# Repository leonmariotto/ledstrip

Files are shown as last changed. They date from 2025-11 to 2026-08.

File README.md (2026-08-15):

# Led Strip Project !

The goal here is to make a led strip controller board that just work.
Among other things the controller include a 3S battery and 4 potentiometer to control
RGBW independently.

The project layout is :
- hardware: kicad project to make the led strip controller board. Use KiCAD 9.
- cad: printable case for the controller + battery.
- software: software used to control the led strip. 
- ai: a setup to run CLI agent (codex) inside a docker with support for multiple AGENTS.md and support for KiMCP server.
- tools: tool to assist during development. Include KiMCP submodule.

## System requirements

- Must have a on/off switch
- Must have a battery properly scaled.
- Must provide a way to control color independently.
- Leds must be RGB with controllable intensity.
- Must provide a way to charge battery
- Must provide a way to program internal flash of MCU.
- Must be enclosed by a case.

## First board

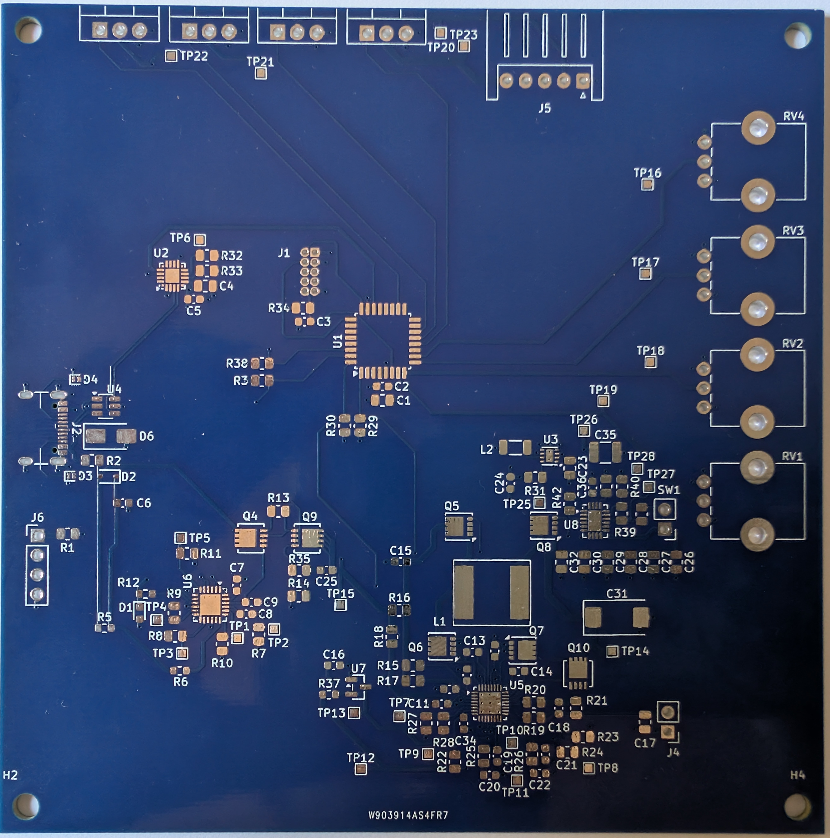
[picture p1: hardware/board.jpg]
Board without components


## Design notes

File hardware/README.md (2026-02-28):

# Hardware design for led strip controller !

## Hardware Requirements

- Must have a on/off switch
- Must provide a USB-C socket
- Must use a serie of Li-Ion battery along with a BMS
- Must use USB-C Power Delivery feature for efficient charging.
- Must use one potentiometer to control one color.
- Must provide an easy access to log via USB.
- Must support run while charging battery.
- Must provide protections against heating and short circuit.

## Ledstrip part !

Choosen RGBW ledstrip of 2 meters.
https://opencircuit.fr/produit/analog-rgbw-led-strip-rgb-plus-warm-white-60

## Hardware Architecture Design

So far the following components is identified :
- 3S Li-ion battery pack. 12V output.
- 3S BMS: off the shelf 3S (3-cells) BMS module. Shall support currents >
to expected (for 2 meter strip the expected current is 3.2A at 12V. So design it to 5-10A.
Start with an external BMS module, then progressively move into an integrated
BMS.
- USB-C connector
- USB to UART bridge (Silicon Labs CP2102(N), or FTDI FT230x or CH340)
- USB Power Delivery controller (ST STUSB4500) used to negociate high power input from USB.
- Battery charger IC (BQ25703A) : accept PD voltage and implement CC/CV.
Provide support for system load while charging.
- Buck regulator (12V to 3.3V) : integrated converter IC
- Logic-level N-MOSFETS x3, low RDS(on).
- Gate resistor / gate pull-down for each MOSFET, Fuse, ESD protections (TVS diodes, Schottky),
- Dedicated MIPI-10 connector for SWD.
- STM32G030K6 MCU.

### STM32G030K6 32-bit LQFP package

Use the following wiring :
- SWD: PA13, PA14, NRST
- UART: PA9 (TX), PA10 (RX)
- ADC (pots): PA0, PA1, PA2
- I2C to BQ25703A: PB6 (SCL), PB7 (SDA)
- PWM to MOSFET: PA8, PA6, PA7
- Power pins: VDD, VDDA, VSS, VSSA (decouple properly)
- BQ25703A_PROCHOT: PB9
- BQ25703A_CHRG_OK: PB9
Note that PWM need to use TIM1 for PA0 and TIM3 for PA6 and PA7 due to conflicts with UART.

## Building

A CI is here to build Gerber on a stable and reproducible environment.
PCBway is the recommended manufacturer.

## 4 layers

- Top (F.Cu): components + most routing (especially short local routes)
- Inner 1: solid GND plane (no splits)
- Inner 2: power pours (3.3 V, 12 V) + only necessary routing (prefer short, controlled routes)
- Bottom (B.Cu): routing + GND pour (stitched to Inner 1 often); use power pours only where it clearly helps (short distribution or local planes)

# TODO

- Create missing 3D view for footprint that lack it.
- MPN (Manufacturer Part Number) shall be included in the CI's BOM
- Generate Pick & Place (CPL/XY)
- Generate Plot Assembly Drwaing (Top/Bottom)

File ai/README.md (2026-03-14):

# AI

This setup use codex inside a container. Only this repository are visible to AI agent.
This have the advantage to give full-access to agent without security issue.
This setup support customizable AGENTS.md.

## Setup

First thing to do is to build the docker image. Go to `ai/docker` and run `./build.sh`.
Dockerfile will look for a `auth.json` file which is not committed.
You'll have to first login to codex elsewhere, and copy `auth.json` here.

## KiCad MCP server

You'll find a submodule under `tools/kimcp` that contain a MCP server implementation
for KiCad.
Container is already setup to try connect to this server.
Start the MCP server before running agents.

## Run

For usage run `ai/run.sh -h`.
Samples AGENTS.md are located in `ai/agents`.
To run with a custom agent : `./ai/run.sh -a ai/agents/kicad_helper.md`.

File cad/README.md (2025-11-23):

# CAD for led strip project !

## CAD requirements

- A plastic case must enclose PCB and battery.
- USB and LED socket shall be accessible from outside the case.
- The case must be easily disassembled using screw.
- Case must be printable on most 3D printers.

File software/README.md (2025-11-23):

# Software design for led strip controller !

## Prototype hardware list

- STM32G0 nucleo
- Led strip
- 3 potentiometer
- 3 N-channel mosfet

## Software Requirements

- Must read analog input from potentiometer.
- Must control N-channel mosfet with PWM.
- Must output log on UART.
- Must drive battery charger IC.

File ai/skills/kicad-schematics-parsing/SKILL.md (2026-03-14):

---
name: kicad-schematics-parsing
description: Parse KiCad schematics file in order to extract data or modify it.
---

# kicad-schematics-parsing

How to extract or modify data in KiCad schematics (`.kicad_sch`) without the GUI.

## Choose the interface first
- Use `kicad-cli` export plus direct `.kicad_sch` parsing for audits, field completeness, BOM/MPN checks, and low-level bulk edits.
- Use the KiCad schematic MCP server for semantic edits: add/remove components, inspect pins, add labels/wires/buses, connect pins, manage sheets, then save.
- Prefer plain parsing when correctness depends on raw file contents or when the MCP wrapper looks stale or buggy.
- Prefer MCP when the task is naturally schematic-aware, such as "connect U1 pin PB6 to R3 pin 1" or "add a resistor and label the net".

## Export structured data first
- Prefer exporting to XML (easy to parse) with `HOME=$PWD kicad-cli sch export netlist --format kicadxml
<schematic> -o /tmp/netlist.xml`.
- If the project uses custom libs, run in the project root so the project `sym-lib-table` is found. Setti
ng `HOME` to the repo avoids permission errors from KiCad trying to write under `/root`.
- For BOM-style field checks, `kicad-cli sch export bom <schematic> -o /tmp/bom.csv` can be simpler.
- Treat XML/BOM export as a first pass, not a source of truth for every custom field value. In some proje
cts the export preserves field names but drops populated per-symbol values needed for audits.

## Parsing tips (XML netlist)
- Components live under `<export><components><comp ref=...>`. Within each `<comp>` you have `<value>`, `<
footprint>`, `<description>`, `<fields>` (legacy fields) and `<property>` entries (modern properties).
- When reading a field/property, prefer `property` value, and fall back to `fields/field` if missing. Bot
h use the `name` attribute.
- Sheet hierarchy is exposed by `<sheetpath>` attributes if you need context per component.
- If expected custom values come back empty, switch to parsing the `.kicad_sch` directly before concluding
 the data is missing.

## Parsing tips (S-expression `.kicad_sch`)
- Each schematic is an S-expression rooted at `(kicad_sch ...)` with sections such as `(lib_symbols ...)`
 and many placed top-level `(symbol ...)` instances.
- Library symbols may appear under `(lib_symbols ...)`, but placed symbol instances are usually top-level `
(symbol ...)` blocks with `(property "Reference" "...")`, `(property "Value" "...")`, etc. Audit those in
stance blocks, not the library symbol definitions.
- Properties mirror what you see in XML export (`Distributor Link 1`, `Manufacturer Part Number`, etc.).
- Use an S-expression parser when available; if not, a small purpose-built parser for strings/lists is fin
e. Treat text as UTF-8.
- For edits, preserve formatting and numeric precision; KiCad is order-tolerant but stable ordering reduc
es churn.
- Ignore autosave or lock files such as `_autosave-*.kicad_sch` and `~*.lck` unless the user explicitly wa
nts them audited.

## MCP workflow
- Load the target schematic through the MCP server before making semantic edits.
- After loading, inspect with MCP methods such as component listing and pin lookup instead of recomputing symbol geometry yourself.
- For wire creation, prefer MCP connection helpers over hand-editing wires and junctions.
- Save through MCP, then validate with `kicad-cli sch export netlist` and ERC.
- If MCP fails on the real project, fall back immediately to plain parsing and `kicad-cli`; do not block on the wrapper.

## When plain parsing is better
- Auditing custom properties like `Distributor Link 1`, `Manufacturer Part Number`, and footprint completeness.
- Normalizing or bulk-editing per-symbol properties across many instances.
- Investigating hierarchy, formatting, or unusual constructs exactly as stored on disk.
- Working around MCP wrapper/API mismatches.

## Common queries
- Symbols missing a property: filter comps where `property["TargetProp"]` is empty but another property e
xists.
- Footprint completeness: ensure `Footprint`/`footprint` is set on every symbol unless intentionally excl
uded (`exclude_from_bom`/`exclude_from_board`).
- Link/MPN completeness: ensure `Distributor Link 1` and `Manufacturer Part Number` are filled for all pu
rchasing parts; headers/testpoints may be exempt.
- For link/MPN audits, check common misspellings seen in hand-edited projects too: `Distributor Link 1`, `
Disributor Link 1`, and `Ditributor Link 1`.
- Treat `Manufacturer Part Number` and `MPN` as equivalent by default; normalize field names before compar
ing.
- If a part has a distributor URL but no MPN field, you can often guess the MPN and manufacturer from the
 URL path. Example: Mouser links usually encode `/ProductDetail/<Manufacturer>/<MPN>`, DigiKey links often
 encode `/detail/<manufacturer>/<mpn>/...`, and vendor datasheet URLs may expose the MPN in the filename.

## Editing safely
- For small changes, edit the `.kicad_sch` S-expression directly: update `(property "Name" "Value")` or a
dd missing ones inside the symbol block.
- When adding properties, keep the same quoting and spacing as neighbors; avoid KiCad-specific tokens lik
e `~` unless already used.
- After edits, re-export with `kicad-cli sch export netlist --format kicadxml ...` and sanity-check count
s/fields.
- When backfilling procurement data, prefer updating the existing per-symbol instance properties instead of
 changing only library symbols.

## MCP patching notes
- Treat the MCP server as a thin wrapper around `kicad_sch_api`; if a tool fails with an attribute error, inspect the wrapper before blaming the schematic.
- Reproduce failures through the underlying Python API when possible. If `kicad_sch_api.Schematic.load(...)` works but the MCP tool fails, the bug is in the wrapper.
- In this environment, `title_block` is a `dict`, so wrapper code must use `schematic.title_block.get("title")`, not `schematic.title_block.title`.
- In this environment, some wrapper code assumed `schematic.lib_symbols` existed; use `schematic._data.get("lib_symbols", {})` if the public property is missing.
- `manage_power` is currently suspect here because the wrapper calls a missing `add_power_symbol` method. Use labels or direct file edits as fallback until patched.
- After patching the MCP server, verify by calling the exact MCP path again, not just the lower-level library.

## Checks
- ERC: `kicad-cli sch erc <schematic>` (may need project libs).
- If KiCad complains about missing global tables, copy/link required libs into the project `sym-lib-table
` or run with `HOME` set to a writable location inside the repo.

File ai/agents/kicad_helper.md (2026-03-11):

# AGENTS.md

You're an agent specialized in understand kicad hardware design projects.
You're able to parse and modify kicad files.
You're able to use kicad-cli to run kicad check.

## Workspace layout

- Project directory is `./ledstrip`. Hardware part of project is located under `hardware`.
- You'll find hardware architecture design description under `hardware/README.md` and in the
drawio schema.

## Helpful commands and checks

- Run ERC: `kicad-cli sch erc hardware/ledstrip/ledstrip.kicad_sch`
- Export BOM: `kicad-cli sch export bom hardware/ledstrip/ledstrip.kicad_sch -o /tmp/ledstrip_bom.xml`
- Export netlist for scripted checks: `kicad-cli sch export netlist hardware/ledstrip/ledstrip.kicad_sch -o /tmp/netlist.xml`
- When auditing completeness, ensure every symbol has a footprint and `Distributor Link 1` (headers/testpoints may intentionally omit distributor links).
- Project-specific library table may be required; copy global libs into the project table before running ERC so symbol libraries resolve.

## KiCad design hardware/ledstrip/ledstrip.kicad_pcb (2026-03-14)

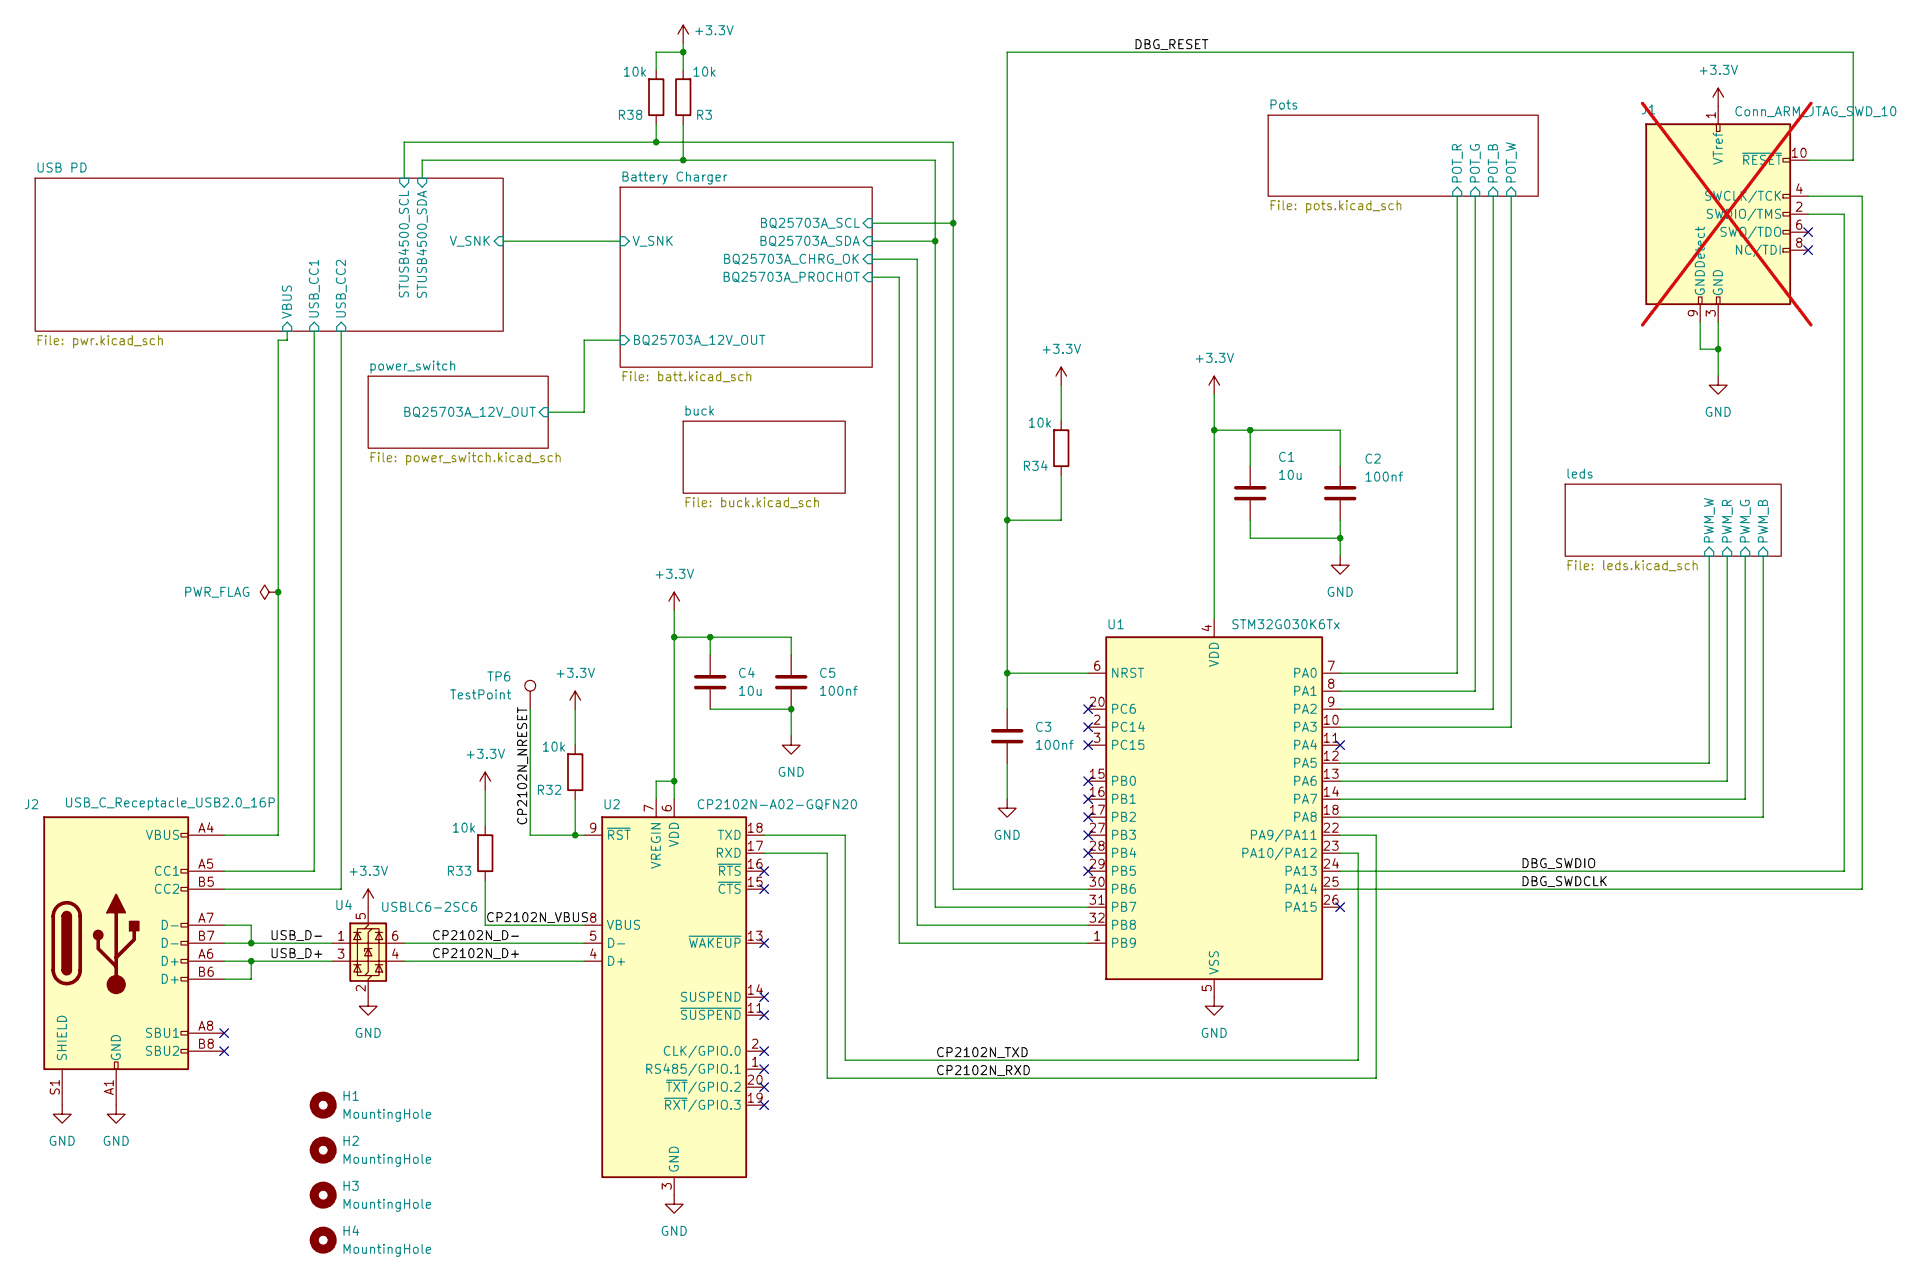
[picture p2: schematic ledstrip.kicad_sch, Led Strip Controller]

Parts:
C1, C4: 10u; C_0805_2012Metric; MPN CL21A106KAYNNN
C2, C3, C5: 100nf; C_0603_1608Metric; MPN CL10B104KA8VPJC
H1, H2, H3, H4: MountingHole; MountingHole_3.2mm_M3
J1: Conn_ARM_JTAG_SWD_10; PinHeader_2x05_P1.27mm_Vertical; not fitted
J2: USB_C_Receptacle_USB2.0_16P; USB_C_Receptacle_GCT_USB4105-xx-A_16P_TopMnt_Horizontal_PRO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; MPN USB4105-GF-A-060
R3, R32, R33, R34, R38: 10k; R_0805_2012Metric; MPN MCU0805MD1002BP500
TP6: TestPoint; TestPoint_Pad_1.0x1.0mm
U1: STM32G030K6Tx; LQFP-32_7x7mm_P0.8mm; MPN STM32G030K6T6
U2: CP2102N-A02-GQFN20; SiliconLabs_QFN-20-1EP_3x3mm_P0.5mm_EP1.8x1.8mm; MPN CP2102N-A02-GQFN20
U4: USBLC6-2SC6; SOT-23-6; MPN USBLC6-2SC6

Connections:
+3.3V: C1.1, C2.1, C4.1, C5.1, J1.1 (VTref), R3.2, R32.2, R33.2, R34.2, R38.2, U1.4 (VDD), U2.6 (VDD), U2.7 (VREGIN), U4.5 (VBUS); also elsewhere on the board
/Battery Charger/BQ25703A_CHRG_OK: U1.32 (PB8); also elsewhere on the board
/Battery Charger/BQ25703A_PROCHOT: U1.1 (PB9); also elsewhere on the board
/Battery Charger/BQ25703A_SCL: R38.1, U1.30 (PB6); also elsewhere on the board
/Battery Charger/BQ25703A_SDA: R3.1, U1.31 (PB7); also elsewhere on the board
/CP2102N_D+: U2.4 (D+), U4.4 (I/O2)
/CP2102N_D-: U2.5 (D-), U4.6 (I/O1)
/CP2102N_NRESET: R32.1, TP6.1, U2.9 (~RST)
/CP2102N_RXD: U1.22 (PA9/PA11), U2.17 (RXD)
/CP2102N_TXD: U1.23 (PA10/PA12), U2.18 (TXD)
/CP2102N_VBUS: R33.1, U2.8 (VBUS)
/DBG_RESET: C3.1, J1.10 (~RESET), R34.1, U1.6 (NRST)
/DBG_SWDCLK: J1.4 (SWCLK/TCK), U1.25 (PA14)
/DBG_SWDIO: J1.2 (SWDIO/TMS), U1.24 (PA13)
/Pots/POT_B: U1.9 (PA2); also elsewhere on the board
/Pots/POT_G: U1.8 (PA1); also elsewhere on the board
/Pots/POT_R: U1.7 (PA0); also elsewhere on the board
/Pots/POT_W: U1.10 (PA3); also elsewhere on the board
/USB PD/USB_CC1: J2.A5 (CC1); also elsewhere on the board
/USB PD/USB_CC2: J2.B5 (CC2); also elsewhere on the board
/USB PD/VBUS: J2.A4 (VBUS), J2.A9 (VBUS), J2.B4 (VBUS), J2.B9 (VBUS); also elsewhere on the board
/USB_D+: J2.A6 (D+), J2.B6 (D+), U4.3 (I/O2)
/USB_D-: J2.A7 (D-), J2.B7 (D-), U4.1 (I/O1)
/leds/PWM_B: U1.18 (PA8); also elsewhere on the board
/leds/PWM_G: U1.14 (PA7); also elsewhere on the board
/leds/PWM_R: U1.13 (PA6); also elsewhere on the board
/leds/PWM_W: U1.12 (PA5); also elsewhere on the board
GND: C1.2, C2.2, C3.2, C4.2, C5.2, J1.3 (GND), J1.5 (GND), J1.9 (GNDDetect), J2.A1 (GND), J2.A12 (GND), J2.B1 (GND), J2.B12 (GND), J2.S1 (SHIELD), U1.5 (VSS), U2.3 (GND), U2.12 (GND), U2.21 (GND), U4.2 (GND); also elsewhere on the board

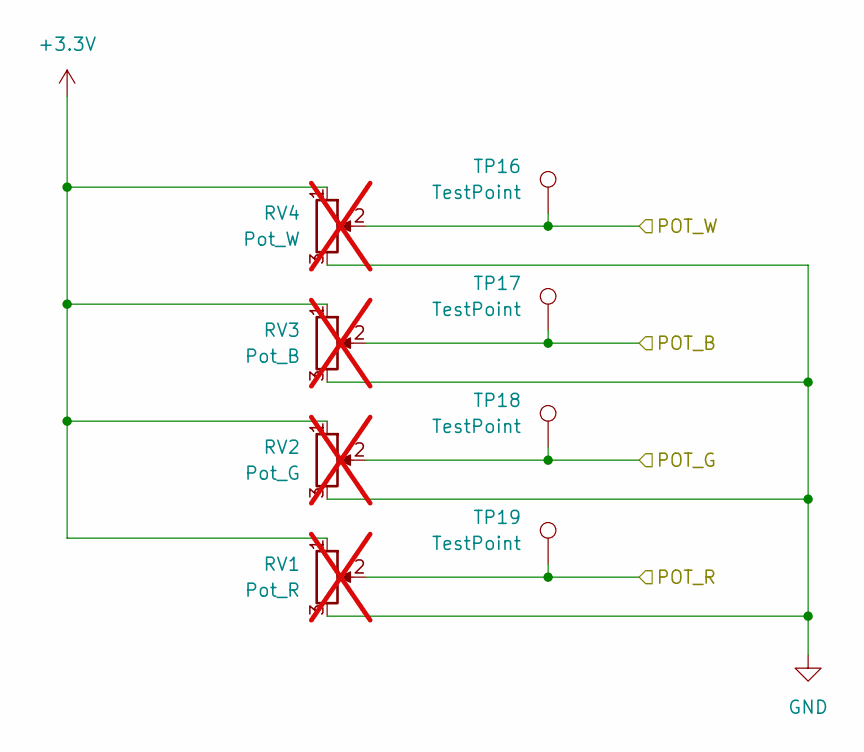
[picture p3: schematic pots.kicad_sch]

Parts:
RV1: Pot_R; Potentiometer_Bourns_PTV09A-1_Single_Vertical; MPN PTV09A-6030U-B103; not fitted
RV2: Pot_G; Potentiometer_Bourns_PTV09A-1_Single_Vertical; MPN PTV09A-6030U-B103; not fitted
RV3: Pot_B; Potentiometer_Bourns_PTV09A-1_Single_Vertical; MPN PTV09A-6030U-B103; not fitted
RV4: Pot_W; Potentiometer_Bourns_PTV09A-1_Single_Vertical; MPN PTV09A-6030U-B103; not fitted
TP16, TP17, TP18, TP19: TestPoint; TestPoint_Pad_1.0x1.0mm

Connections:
+3.3V: RV1.1, RV2.1, RV3.1, RV4.1; also elsewhere on the board
/Pots/POT_B: RV3.2, TP17.1; also elsewhere on the board
/Pots/POT_G: RV2.2, TP18.1; also elsewhere on the board
/Pots/POT_R: RV1.2, TP19.1; also elsewhere on the board
/Pots/POT_W: RV4.2, TP16.1; also elsewhere on the board
GND: RV1.3, RV2.3, RV3.3, RV4.3; also elsewhere on the board

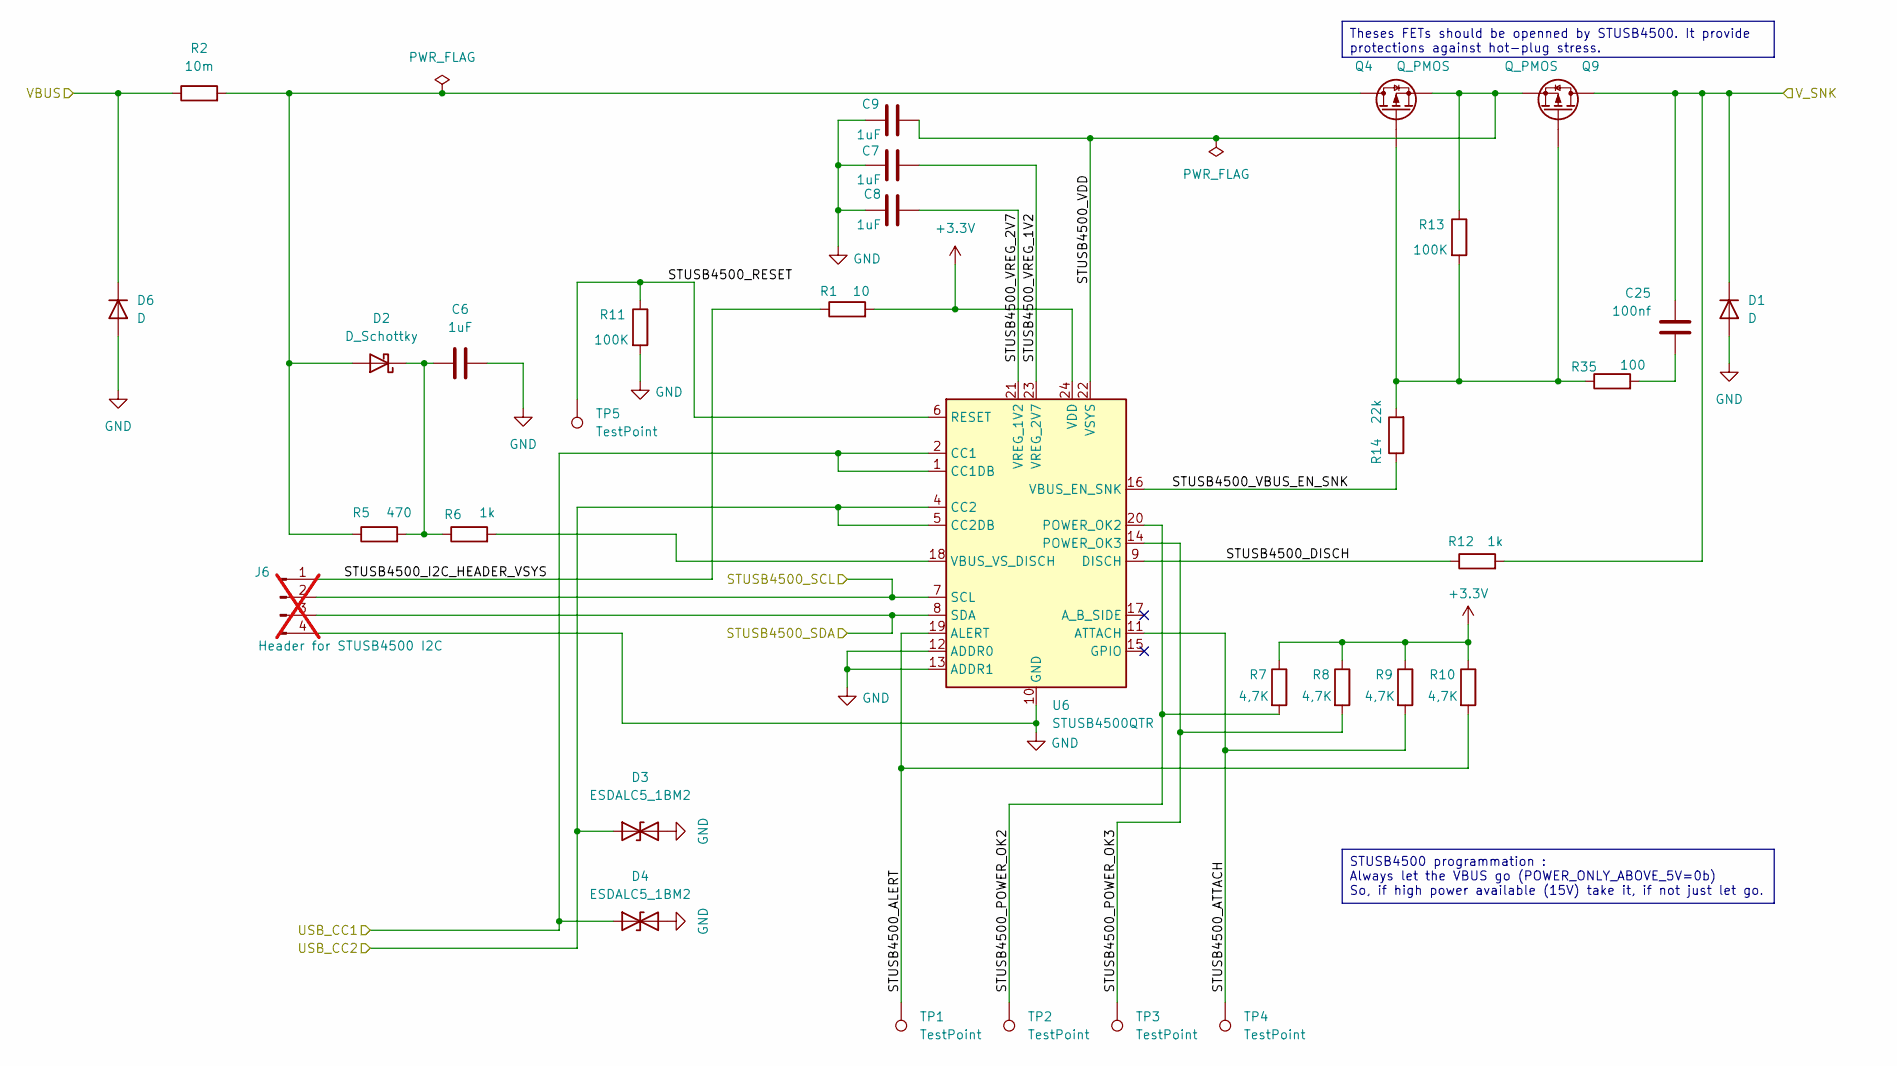
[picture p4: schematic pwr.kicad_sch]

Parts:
C6, C7, C8, C9: 1uF; C_0603_1608Metric; MPN 885012106022
C25: 100nf; C_0603_1608Metric; MPN CL10B104KA8VPJC
D1: D; D_0603_1608Metric; MPN ESDA20P50-1U1M
D2: D_Schottky; D_SOD-323; MPN BAT54JFILM
D3, D4: ESDALC5_1BM2; D_SOD-882; MPN ESDALC5-1BT2
D6: D; D_SMA; MPN SMAJ15AHM3_A-H
J6: Header for STUSB4500 I2C; PinHeader_1x04_P2.54mm_Vertical; not fitted
Q4, Q9: Q_PMOS; POWERFLAT_3P3X3P3_STM; MPN STL6P3LLH6
R1: 10; R_0805_2012Metric; MPN CRCW080510R0JNEAHP
R2: 10m; R_0805_2012Metric; MPN WSLP0805R0100DEA
R5: 470; R_0603_1608Metric; MPN SFR03EZPJ471
R6, R12: 1k; R_0603_1608Metric; MPN RCA06031K00FKEAHP
R7, R8, R9, R10: 4,7K; R_0805_2012Metric; MPN ERA-6ARW472V
R11, R13: 100K; R_0805_2012Metric; MPN RT0805BRB07100KL
R14: 22k; R_0805_2012Metric; MPN MCU08050C2202FP500
R35: 100; R_0805_2012Metric; MPN RP0805CT-1000GN-96TR
TP1, TP2, TP3, TP4, TP5: TestPoint; TestPoint_Pad_1.0x1.0mm
U6: STUSB4500QTR; QFN-24-1EP_4x4mm_P0.5mm_EP2.7x2.7mm; MPN STUSB4500QTR

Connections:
+3.3V: R1.2, R7.1, R8.1, R9.1, R10.1, U6.24 (VDD); also elsewhere on the board
/Battery Charger/BQ25703A_SCL: J6.2, U6.7 (SCL); also elsewhere on the board
/Battery Charger/BQ25703A_SDA: J6.3, U6.8 (SDA); also elsewhere on the board
/Battery Charger/V_SNK: C25.1, D1.1 (K), Q9.D, R12.2; also elsewhere on the board
/USB PD/STUSB4500_ALERT: R10.2, TP1.1, U6.19 (ALERT)
/USB PD/STUSB4500_ATTACH: R9.2, TP4.1, U6.11 (ATTACH)
/USB PD/STUSB4500_DISCH: R12.1, U6.9 (DISCH)
/USB PD/STUSB4500_I2C_HEADER_VSYS: J6.1, R1.1
/USB PD/STUSB4500_POWER_OK2: R7.2, TP2.1, U6.20 (POWER_OK2)
/USB PD/STUSB4500_POWER_OK3: R8.2, TP3.1, U6.14 (POWER_OK3)
/USB PD/STUSB4500_RESET: R11.1, TP5.1, U6.6 (RESET)
/USB PD/STUSB4500_VBUS_EN_SNK: R14.1, U6.16 (VBUS_EN_SNK)
/USB PD/STUSB4500_VDD: C9.2, Q4.S, Q9.S, R13.1, U6.22 (VSYS)
/USB PD/STUSB4500_VREG_1V2: C7.1, U6.23 (VREG_2V7)
/USB PD/STUSB4500_VREG_2V7: C8.1, U6.21 (VREG_1V2)
/USB PD/USB_CC1: D4.1 (A1), U6.1 (CC1DB), U6.2 (CC1); also elsewhere on the board
/USB PD/USB_CC2: D3.1 (A1), U6.4 (CC2), U6.5 (CC2DB); also elsewhere on the board
/USB PD/VBUS: D6.1 (K), R2.1; also elsewhere on the board
GND: C6.2, C7.2, C8.2, C9.1, D1.2 (A), D3.2 (A2), D4.2 (A2), D6.2 (A), J6.4, R11.2, U6.10 (GND), U6.12 (ADDR0), U6.13 (ADDR1), U6.25 (GND); also elsewhere on the board
unnamed: C25.2, R35.2
unnamed: D2.2 (A), Q4.D, R2.2, R5.1
unnamed: C6.1, D2.1 (K), R5.2, R6.1
unnamed: Q4.G, Q9.G, R13.2, R14.2, R35.1
unnamed: R6.2, U6.18 (VBUS_VS_DISCH)

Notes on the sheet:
Theses FETs should be openned by STUSB4500. It provide protections against hot-plug stress.
STUSB4500 programmation : Always let the VBUS go (POWER_ONLY_ABOVE_5V=0b) So, if high power available (15V) take it, if not just let go.

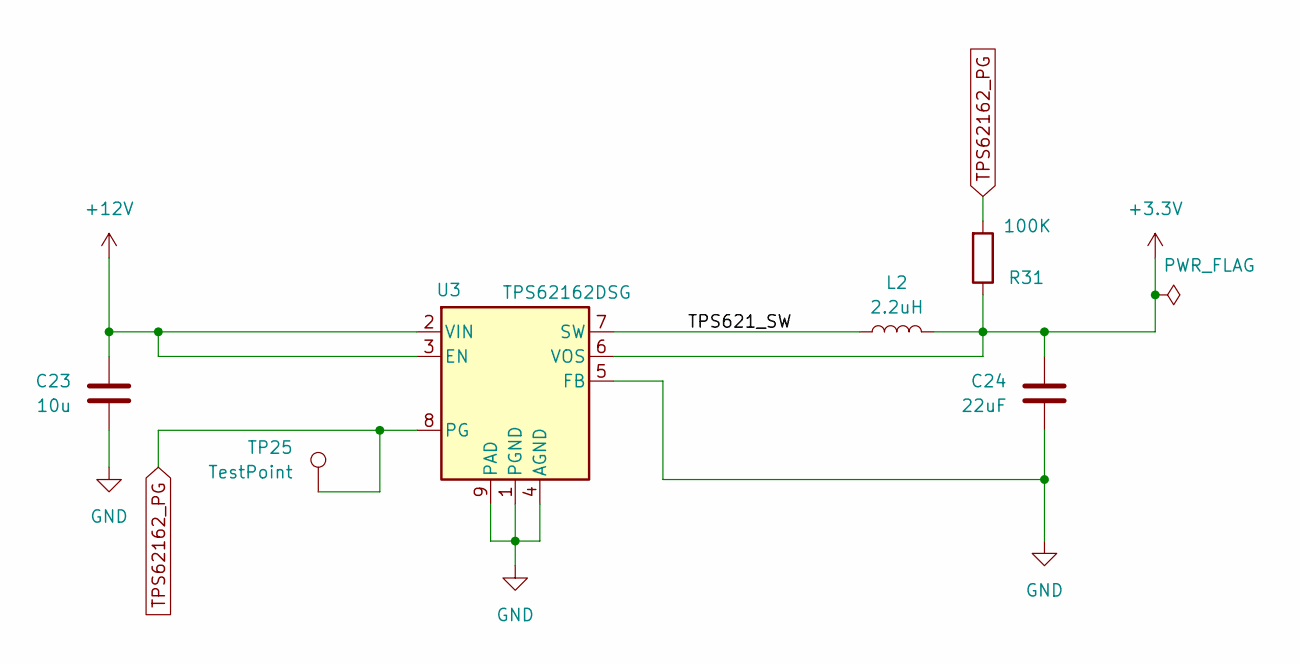
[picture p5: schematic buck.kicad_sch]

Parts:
C23: 10u; C_0805_2012Metric; MPN CL21A106KAYNNN
C24: 22uF; C_0603_1608Metric; MPN CL10Z226MS96PNC
L2: 2.2uH; L_1206_3216Metric; MPN PFL3215-222MEC
R31: 100K; R_0805_2012Metric; MPN RT0805BRB07100KL
TP25: TestPoint; TestPoint_Pad_1.0x1.0mm
U3: TPS62162DSG; WSON-8-1EP_2x2mm_P0.5mm_EP0.9x1.6mm_ThermalVias; MPN TPS62162DSGT

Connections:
+3.3V: C24.1, L2.2, R31.1, U3.6 (VOS); also elsewhere on the board
+12V: C23.1, U3.2 (VIN), U3.3 (EN); also elsewhere on the board
/buck/TPS621_SW: L2.1, U3.7 (SW)
GND: C23.2, C24.2, U3.1 (PGND), U3.4 (AGND), U3.5 (FB), U3.9 (PAD); also elsewhere on the board
TPS62162_PG: R31.2, TP25.1, U3.8 (PG)

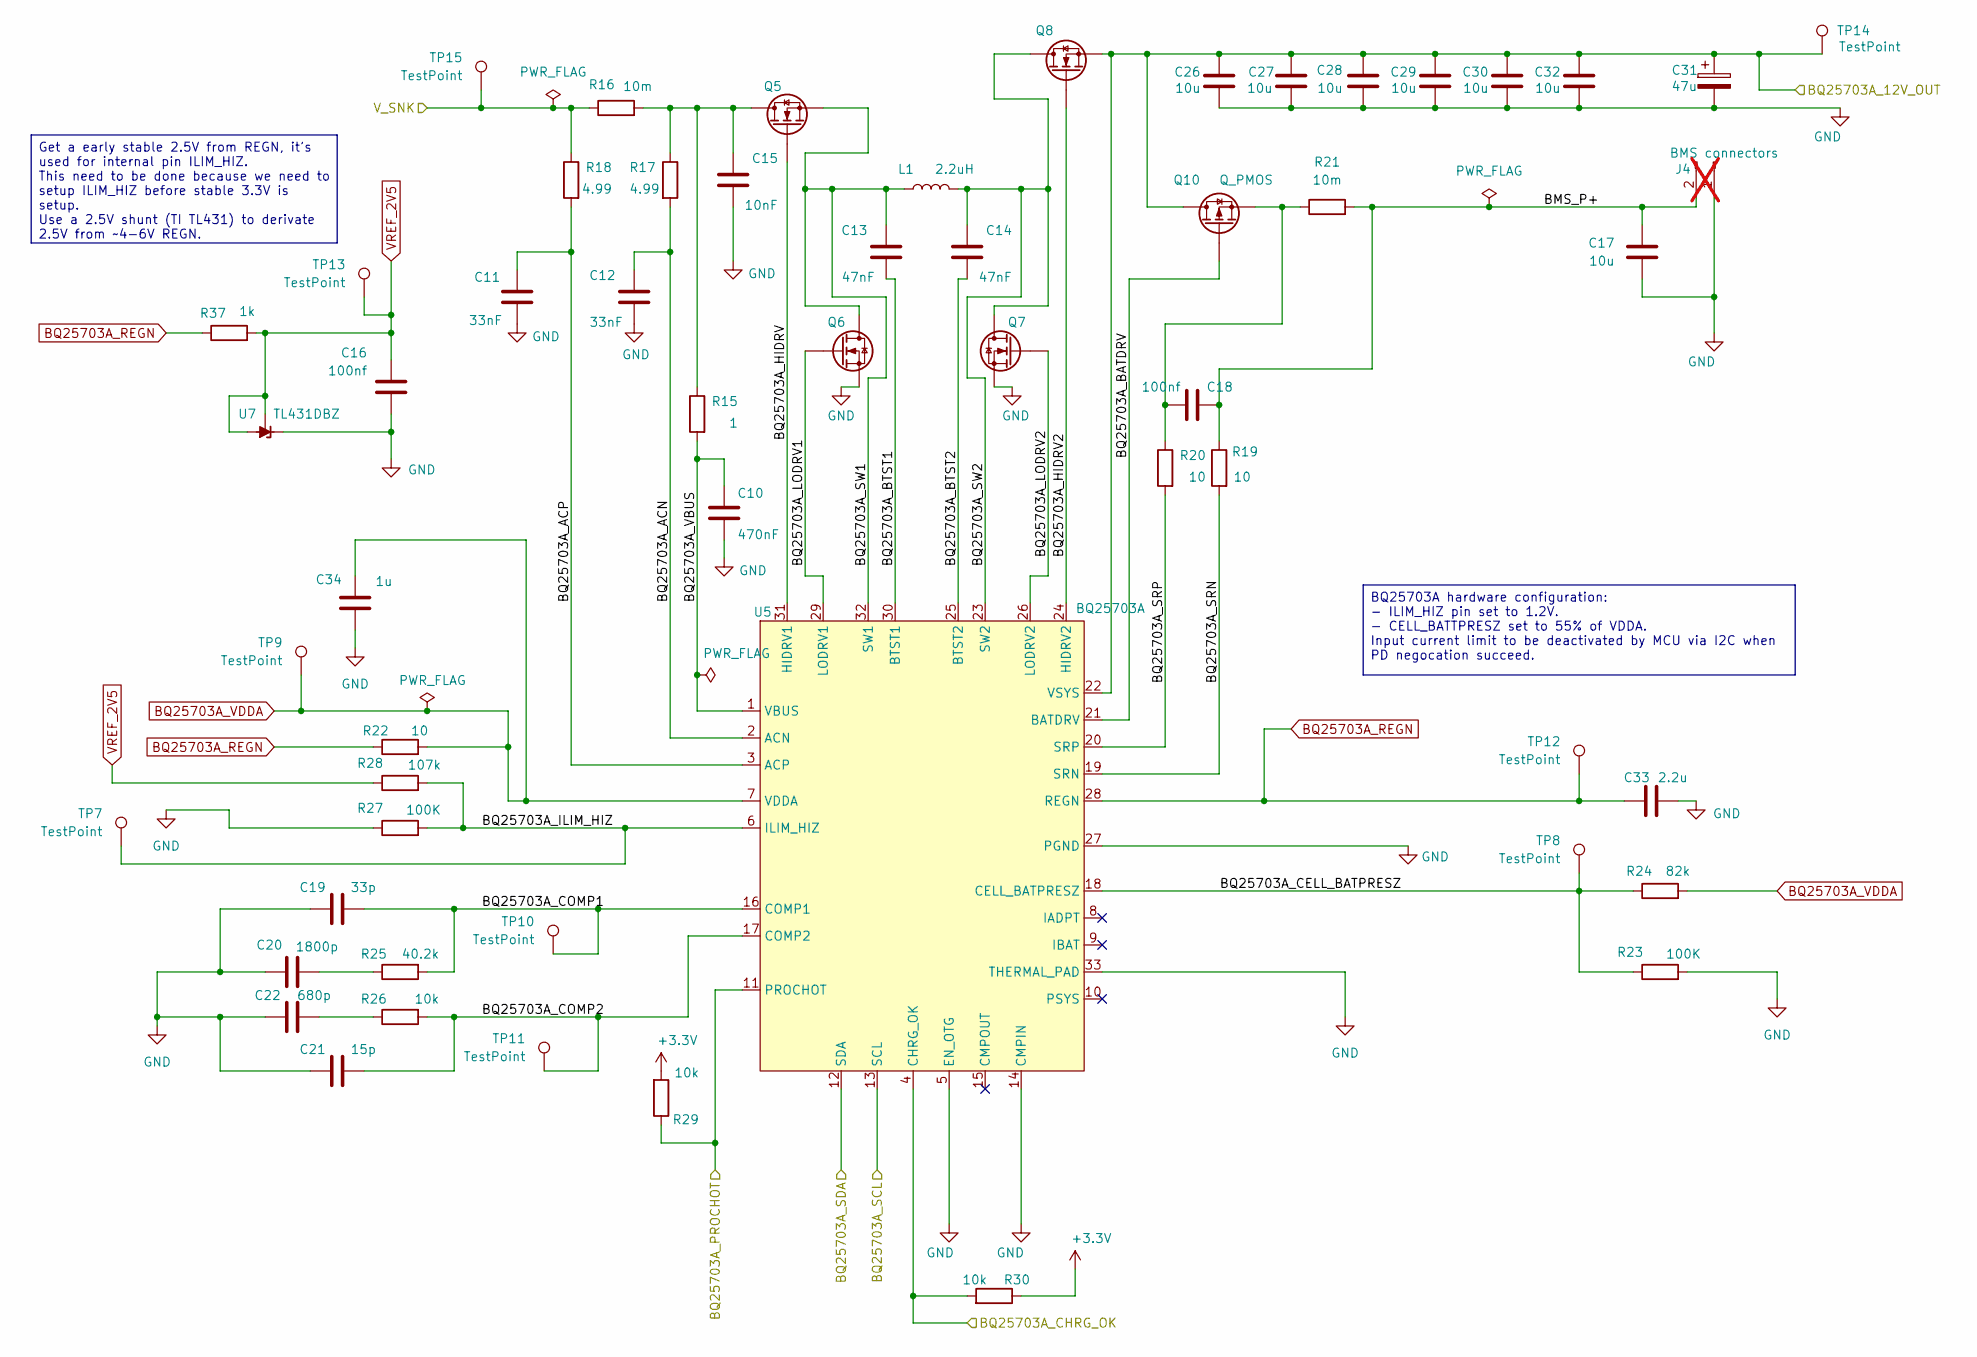
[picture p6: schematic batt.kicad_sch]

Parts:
C10: 470nF; C_0603_1608Metric; MPN C0603C474J3RACTU
C11, C12: 33nF; C_0603_1608Metric; MPN 06031C333KAT2A
C13, C14: 47nF; C_0603_1608Metric; MPN KGM15AR51V473KT
C15: 10nF; C_0603_1608Metric; MPN 03028-BR103YKU-J
C16, C18: 100nf; C_0603_1608Metric; MPN CL10B104KA8VPJC
C17, C26, C27, C28, C29, C30, C32: 10u; C_0805_2012Metric; MPN CL21A106KAYNNN
C19: 33p; C_0603_1608Metric; MPN KGQ15ACG2A330GT
C20: 1800p; C_0603_1608Metric; MPN VJ0603Y182JXAAC
C21: 15p; C_0603_1608Metric; MPN 06031U150JAT2A
C22: 680p; C_0603_1608Metric; MPN VJ0603A681GXAAC
C31: 47u; CP_EIA-7343-20_Kemet-V; MPN 20TQC47MYF
C33: 2.2u; C_0603_1608Metric; MPN CL03A225MO5C65C
C34: 1u; C_0603_1608Metric; MPN AMK063AC6105MP-F
J4: BMS connectors; PinHeader_1x02_P2.54mm_Vertical; not fitted
L1: 2.2uH; L_Wurth_WE-LHMI-8030_9.7x8.5mm; MPN 74437356022
Q5, Q6, Q7, Q8: Q_NMOS; VSON-8_3.3x3.3mm_P0.65mm_NexFET; MPN CSD17551Q3A
Q10: Q_PMOS; POWERFLAT_3P3X3P3_STM; MPN STL6P3LLH6
R15: 1; R_0805_2012Metric; MPN AC0805FR-071RL
R16, R21: 10m; R_0805_2012Metric; MPN WSLP0805R0100DEA
R17, R18: 4.99; R_0805_2012Metric; MPN CRCW08054R99DKEAHP
R19, R20: 10; R_0805_2012Metric; MPN MCU0805MC1009FP500
R22: 10; R_0805_2012Metric; MPN CRCW080510R0JNEAHP
R23, R27: 100K; R_0805_2012Metric; MPN RT0805BRB07100KL
R24: 82k; R_0805_2012Metric; MPN ERA-6ARB823V
R25: 40.2k; R_0805_2012Metric; MPN PHP00805E40R2BST1
R26, R29, R30: 10k; R_0805_2012Metric; MPN MCU0805MD1002BP500
R28: 107k; R_0805_2012Metric; MPN CRCW0805107KFKEA
R37: 1k; R_0603_1608Metric; MPN RCA06031K00FKEAHP
TP7, TP8, TP9, TP10, TP11, TP12, TP13, TP14, TP15: TestPoint; TestPoint_Pad_1.0x1.0mm
U5: BQ25703A; Texas_RSN_WQFN-32-1EP_4x4mm_P0.4mm_EP2.8x2.8mm_ThermalVias; MPN BQ25703ARSNR
U7: TL431DBZ; SOT-23; MPN TL431AQDBZR

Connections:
+3.3V: R29.2, R30.1; also elsewhere on the board
/Battery Charger/BMS_P+: C17.1, C18.2, J4.2, R19.1, R21.2
/Battery Charger/BQ25703A_12V_OUT: C26.1, C27.1, C28.1, C29.1, C30.1, C31.1, C32.1, Q8.S, Q10.D, TP14.1, U5.22 (VSYS); also elsewhere on the board
/Battery Charger/BQ25703A_ACN: C12.2, R17.2, U5.2 (ACN)
/Battery Charger/BQ25703A_ACP: C11.2, R18.2, U5.3 (ACP)
/Battery Charger/BQ25703A_BATDRV: Q10.G, U5.21 (BATDRV)
/Battery Charger/BQ25703A_BTST1: C13.1, U5.30 (BTST1)
/Battery Charger/BQ25703A_BTST2: C14.1, U5.25 (BTST2)
/Battery Charger/BQ25703A_CELL_BATPRESZ: R23.1, R24.1, TP8.1, U5.18 (CELL_BATPRESZ)
/Battery Charger/BQ25703A_CHRG_OK: R30.2, U5.4 (CHRG_OK); also elsewhere on the board
/Battery Charger/BQ25703A_COMP1: C19.1, R25.2, TP10.1, U5.16 (COMP1)
/Battery Charger/BQ25703A_COMP2: C21.1, R26.2, TP11.1, U5.17 (COMP2)
/Battery Charger/BQ25703A_HIDRV: Q5.G, U5.31 (HIDRV1)
/Battery Charger/BQ25703A_HIDRV2: Q8.G, U5.24 (HIDRV2)
/Battery Charger/BQ25703A_ILIM_HIZ: R27.2, R28.2, TP7.1, U5.6 (ILIM_HIZ)
/Battery Charger/BQ25703A_LODRV1: Q6.G, U5.29 (LODRV1)
/Battery Charger/BQ25703A_LODRV2: Q7.G, U5.26 (LODRV2)
/Battery Charger/BQ25703A_PROCHOT: R29.1, U5.11 (PROCHOT); also elsewhere on the board
/Battery Charger/BQ25703A_SCL: U5.13 (SCL); also elsewhere on the board
/Battery Charger/BQ25703A_SDA: U5.12 (SDA); also elsewhere on the board
/Battery Charger/BQ25703A_SRN: R19.2, U5.19 (SRN)
/Battery Charger/BQ25703A_SRP: R20.2, U5.20 (SRP)
/Battery Charger/BQ25703A_SW1: C13.2, L1.1, Q5.S, Q6.D, U5.32 (SW1)
/Battery Charger/BQ25703A_SW2: C14.2, L1.2, Q7.D, Q8.D, U5.23 (SW2)
/Battery Charger/BQ25703A_VBUS: C10.2, R15.2, U5.1 (VBUS)
/Battery Charger/V_SNK: R16.1, R18.1, TP15.1; also elsewhere on the board
BQ25703A_REGN: C33.1, R22.1, R37.1, TP12.1, U5.28 (REGN)
BQ25703A_VDDA: C34.1, R22.2, R24.2, TP9.1, U5.7 (VDDA)
GND: C10.1, C11.1, C12.1, C15.1, C16.2, C17.2, C19.2, C20.2, C21.2, C22.2, C26.2, C27.2, C28.2, C29.2, C30.2, C31.2, C32.2, C33.2, C34.2, J4.1, Q6.S, Q7.S, R23.2, R27.1, U5.5 (EN_OTG), U5.14 (CMPIN), U5.27 (PGND), U5.33 (THERMAL_PAD), U7.1 (K); also elsewhere on the board
unnamed: C15.2, Q5.D, R15.1, R16.2, R17.1
unnamed: C18.1, Q10.S, R20.1, R21.1
unnamed: C20.1, R25.1
unnamed: C22.1, R26.1
VREF_2V5: C16.1, R28.1, R37.2, TP13.1, U7.2 (REF), U7.3 (A)

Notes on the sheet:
Get a early stable 2.5V from REGN, it's used for internal pin ILIM_HIZ. This need to be done because we need to setup ILIM_HIZ before stable 3.3V is setup. Use a 2.5V shunt (TI TL431) to derivate 2.5V from ~4-6V REGN.
BQ25703A hardware configuration: - ILIM_HIZ pin set to 1.2V. - CELL_BATTPRESZ set to 55% of VDDA. Input current limit to be deactivated by MCU via I2C when PD negocation succeed.

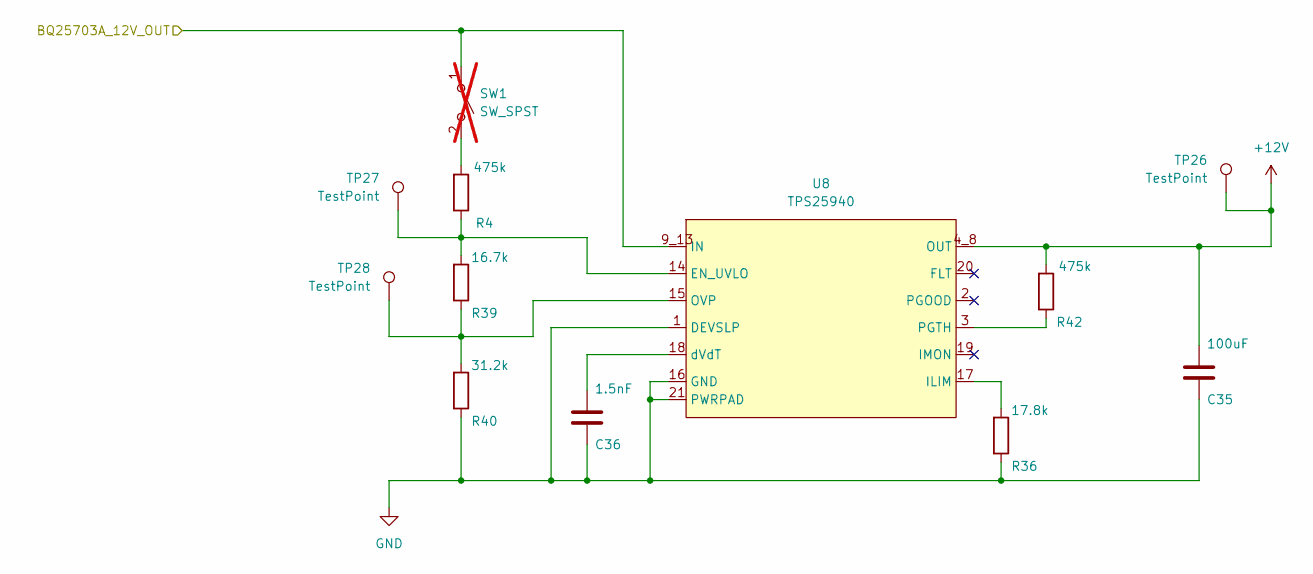
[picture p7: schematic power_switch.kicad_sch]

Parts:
C35: 100uF; C_1210_3225Metric; MPN MLASE32MAB5107MPNA01
C36: 1.5nF; C_0603_1608Metric; MPN GRT033R61A152KE01D
R4, R42: 475k; R_0805_2012Metric; MPN CRCW0805475KFHEAP
R36: 17.8k; R_0805_2012Metric; MPN TNPW080517K8BETY
R39: 16.7k; R_0805_2012Metric; MPN TNPW080516K7BEEN
R40: 31.2k; R_0805_2012Metric; MPN TNPW080531K2BEEN
SW1: SW_SPST; PinHeader_1x02_P2.54mm_Vertical; MPN SW3001A; not fitted
TP26, TP27, TP28: TestPoint; TestPoint_Pad_1.0x1.0mm
U8: TPS25940; QFN-20-1EP_3x4mm_P0.5mm_EP1.65x2.65mm_ThermalVias_PROJECTCO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; MPN TPS25940ARVCT

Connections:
+12V: C35.1, R42.2, TP26.1, U8.4_8 (OUT); also elsewhere on the board
/Battery Charger/BQ25703A_12V_OUT: SW1.1 (A), U8.9_13 (IN); also elsewhere on the board
GND: C35.2, C36.2, R36.1, R40.1, U8.1 (DEVSLP), U8.16 (GND), U8.21 (PWRPAD); also elsewhere on the board
unnamed: R4.2, SW1.2 (B)
unnamed: R4.1, R39.2, TP27.1, U8.14 (EN_UVLO)
unnamed: R36.2, U8.17 (ILIM)
unnamed: R39.1, R40.2, TP28.1, U8.15 (OVP)
unnamed: R42.1, U8.3 (PGTH)
unnamed: C36.1, U8.18 (dVdT)

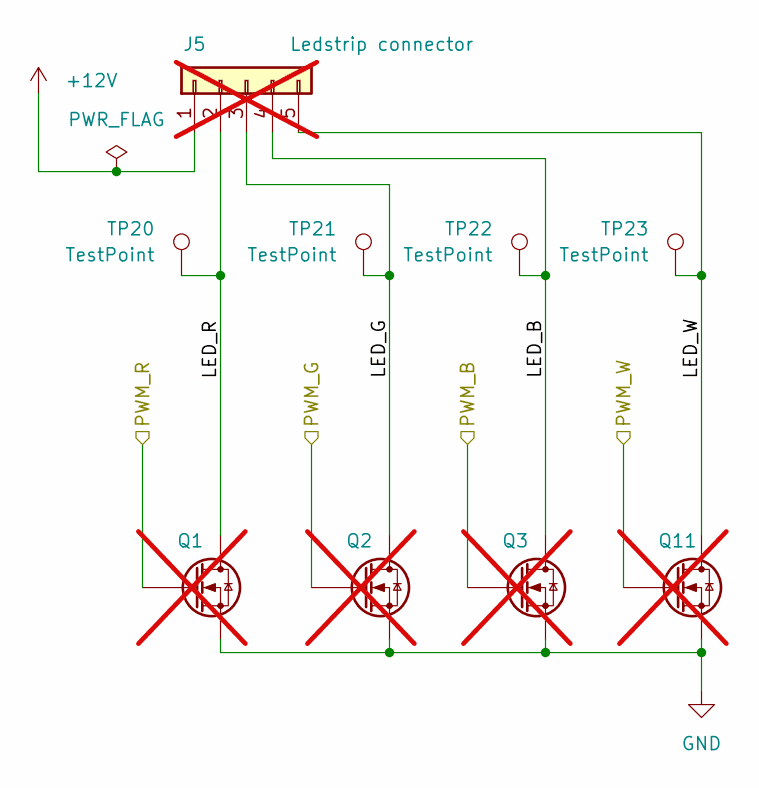
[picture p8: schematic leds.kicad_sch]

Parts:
J5: Ledstrip connector; JST_XH_S5B-XH-A_1x05_P2.50mm_Horizontal; MPN S5B-XH-A-1(LF)(SN); not fitted
Q1, Q2, Q3, Q11: Q_NMOS; TO-220-3_Vertical; MPN IRL3705NPBF; not fitted
TP20, TP21, TP22, TP23: TestPoint; TestPoint_Pad_1.0x1.0mm

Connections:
+12V: J5.1; also elsewhere on the board
/leds/LED_B: J5.4, Q3.D, TP22.1
/leds/LED_G: J5.3, Q2.D, TP21.1
/leds/LED_R: J5.2, Q1.D, TP20.1
/leds/LED_W: J5.5, Q11.D, TP23.1
/leds/PWM_B: Q3.G; also elsewhere on the board
/leds/PWM_G: Q2.G; also elsewhere on the board
/leds/PWM_R: Q1.G; also elsewhere on the board
/leds/PWM_W: Q11.G; also elsewhere on the board
GND: Q1.S, Q2.S, Q3.S, Q11.S; also elsewhere on the board

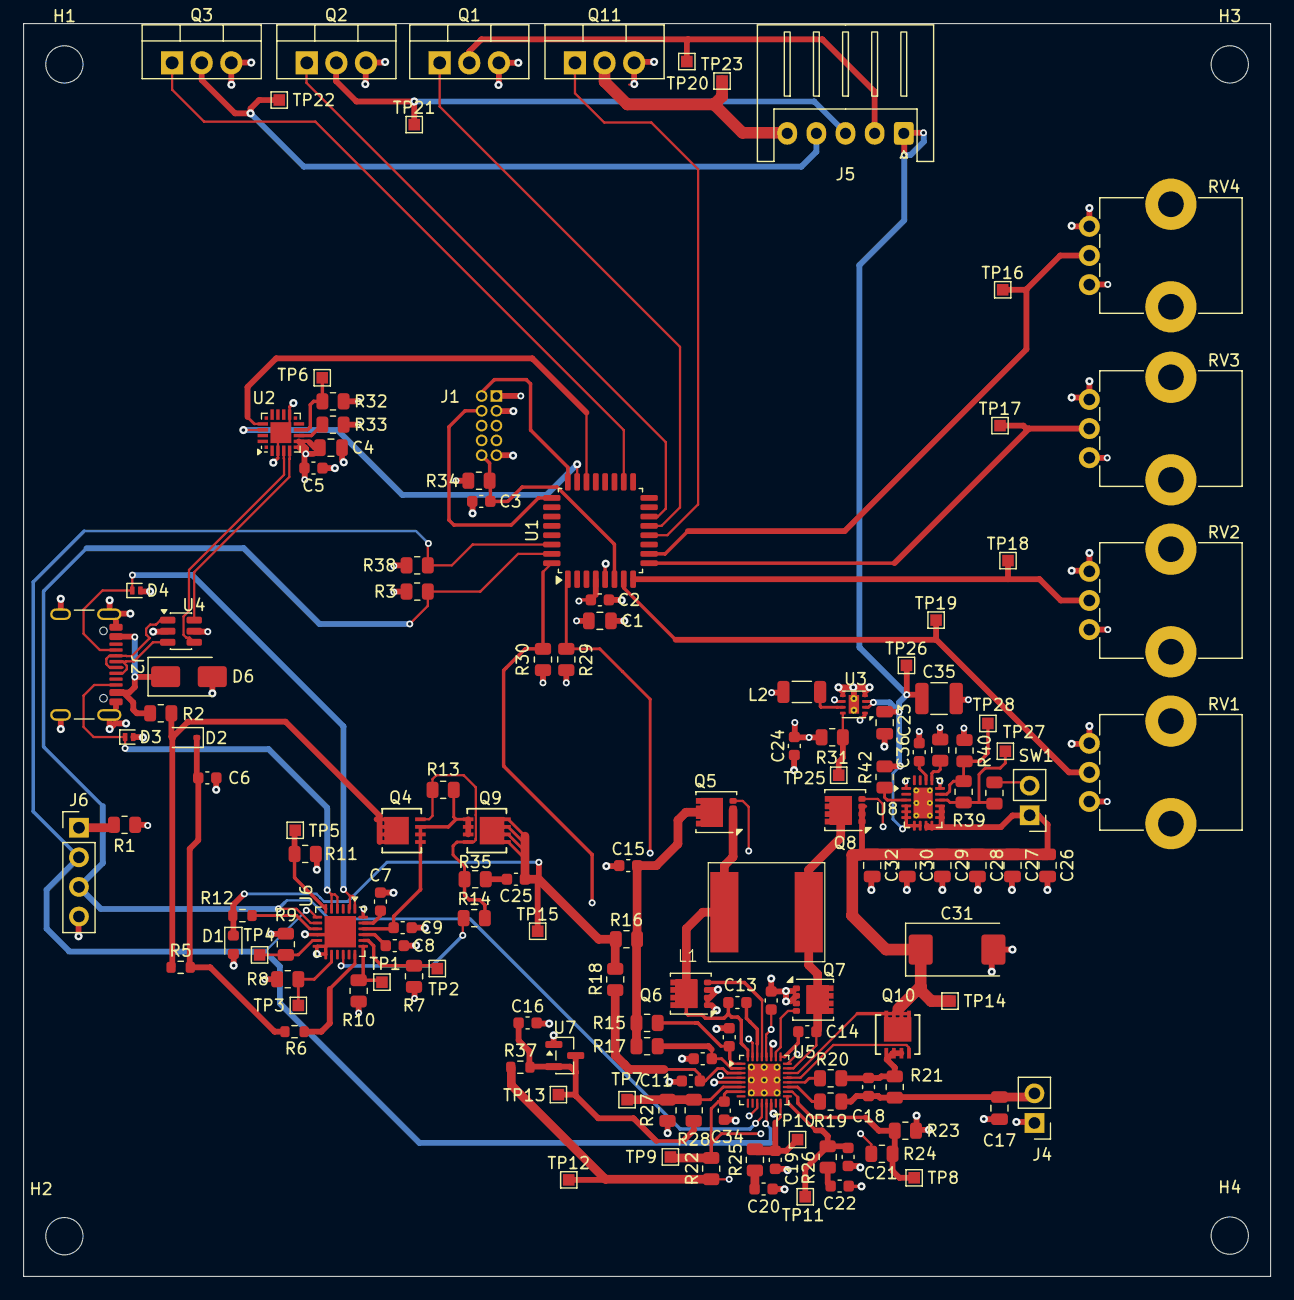
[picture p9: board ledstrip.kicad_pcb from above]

Board: 4 copper layers, 107.0 x 107.5 mm, 144 parts (1 on the bottom side), 85 nets.

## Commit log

2025-11-16 Start kicad project, shcematics ongoing
    MCU integrated
    Still need to do power path
    [ledstrip.kicad_pcb, ledstrip.kicad_sch]
2025-11-20 Minor improvements, add I2C header for STUSB4500
    [ledstrip.kicad_sch]
2025-11-23 Update documentation, add mfor software and CAD
2025-11-23 Add TVS on CC lines, select a footprint for resistors.
    [ledstrip.kicad_sch]
2025-11-30 Sheet rework, new symbols
    Create and add symbol for BQ25703N
    Add symbol for BMS interface
    Add symbol for LED strip socket
    Move power management related things into sub-sheet.
    [ledstrip.kicad_sch, pwr.kicad_sch]
2025-11-30 Select part and add potentiometers to schematics.
    [ledstrip.kicad_sch]
2025-12-02 Add TVS diode on VBUS line, improve STUSB4500 integration
    Add P-MOSFET controled by STUSB4500 on VBUS line
    [ledstrip.kicad_sch, pwr.kicad_sch]
2025-12-06 Add STL6P3LLH6 sym from ulra librarian, add a TODO_plan_for_this_weekend.md for project organization
    [pwr.kicad_sch]
2025-12-06 Finished STUSB4500 integration.
    Improved BQ25703A integration.
    Created a footprint for Wurth inductance.
    [pwr.kicad_sch]
2025-12-06 Splitted into multiple sheets.
    BQ25703A integrated
    buck converter OK
    [batt.kicad_sch, buck.kicad_sch, leds.kicad_sch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]
2025-12-07 Fix ERC errors.
    [batt.kicad_sch, buck.kicad_sch, ledstrip.kicad_sch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]
2025-12-07 AI setup OK.
    Agent is able to parse schematics and verify many things.
2025-12-07 Fix last errors in schematics
    Missing footprint, missing distributor link.
    Updated project sym-lib-table for ERC checks.
    [batt.kicad_sch, buck.kicad_sch, ledstrip.kicad_sch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]
2025-12-09 Add label on nodes.
    [batt.kicad_sch, buck.kicad_sch, leds.kicad_sch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]
2025-12-09 Added a pull down to VSYS
    (external powered if header connected, otherwise VSYS is tied to GND) in STUSB4500 integration.
    [ledstrip.kicad_sch, pwr.kicad_sch]
2025-12-13 Update READMEs
    Choose a manufacturer for the board
    Add some part list : battery pack, external BMS
2025-12-13 Start PCB design !
    Use 4 layers.
    Global options set for PCBWay manufacturer.
    [ledstrip.kicad_pcb]
2025-12-14 Continue PCB.
    Create netlists and color them.
    Fix wrong symbol pin <-> foot print pins mapping.
    Replace footprint and part for leds N-MOSFET.
    [batt.kicad_sch, leds.kicad_sch, ledstrip.kicad_pcb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]
2025-12-14 Fix ERC warnings.
    [batt.kicad_sch, buck.kicad_sch, pwr.kicad_sch]
2025-12-26 Fix ILIM_HIZ setting on BQ25703A
    Add comments on schematics about hardware configuration.
    Setup a early stable 2.5V from REGN to setup ILIM_HIZ correctly.
    [batt.kicad_sch, leds.kicad_sch, ledstrip.kicad_pcb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]
2025-12-26 Wire STUSB4500 I2C to MCU
    [ledstrip.kicad_sch, pwr.kicad_sch]
2026-01-08 Fix ERC errors
    [pwr.kicad_sch]
2026-01-20 Improve footprint placements.
    [ledstrip.kicad_pcb]
2026-01-22 Improve slightly placements.
    Add next step in README.md.
    Add description of layers usages.
    [ledstrip.kicad_pcb]
2026-01-31 Added GND zone in L2 layer + vias for ground.
    [ledstrip.kicad_pcb, ledstrip.kicad_sch]
2026-01-31 Add 3.3V and 12V zones on L3, add vias.
    [ledstrip.kicad_pcb]
2026-02-01 Start editing some trace.
    [ledstrip.kicad_pcb, pwr.kicad_sch]
2026-02-08 All signal tracks done, PCB almost terminated
    Only GND, 3.3V and 12V pins-to-via tracks left.
    [ledstrip.kicad_pcb]
2026-02-27 Add ON/OFF button to PCB.
    Decrease power zone size.
    [batt.kicad_sch, ledstrip.kicad_pcb, ledstrip.kicad_sch]
2026-02-27 Remove power zones, use tracks instead.
    [ledstrip.kicad_pcb]
2026-02-27 Update board parameter, try to reduce DRC errors.
    [ledstrip.kicad_pcb]
2026-02-28 Fix DRC errors
    Reduce globa;l solder mask clearance based on PCBWay limitations
    Fix POWERFLAT_3P3X3P3_STM footprint.
    [ledstrip.kicad_pcb]
2026-02-28 Fix all DRC errors.
    [ledstrip.kicad_pcb]
2026-02-28 Fix ERC and DRC errors.
    Use a custom copy of USB-C in project library to avoid having a version
    mismatch with CI.
    Fix QFN-20-1EP_3x4mm_P0.5mm_EP1.65x2.65mm_ThermalVias mismatch pins.
    Fix ERC errors.
    [leds.kicad_sch, ledstrip.kicad_pcb, ledstrip.kicad_sch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]
2026-03-11 Use my fork of sparkengineering kicad-action.
2026-03-11 Add a BOM preset and set it in CI.
    [batt.kicad_sch, buck.kicad_sch, leds.kicad_sch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]
2026-03-11 Add a part number for USB port
    [ledstrip.kicad_sch]
2026-03-14 Minor fixes
    [batt.kicad_sch, buck.kicad_sch, leds.kicad_sch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]
2026-03-14 Fix AI.
    Update codex version.
    Introduce SKILLS usage: mount skills at the good location.
    Use default codex_config.toml for now.
    Auto-login, auth.json not committed.
2026-03-14 Update schematics symbols fields for manufactrurer
    Update BOM fields.
    [batt.kicad_sch, buck.kicad_sch, leds.kicad_sch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]
2026-03-14 Fix some symbols fields.
    [batt.kicad_sch, leds.kicad_sch, ledstrip.kicad_sch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]
2026-03-14 Fix ERC error
    [batt.kicad_sch, leds.kicad_sch, ledstrip.kicad_sch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]
2026-03-14 Normalize Vishay manufacturer (delete sub-brand)
    [batt.kicad_sch, ledstrip.kicad_sch, pwr.kicad_sch]
2026-03-14 Remove typos and legacy fields
    [batt.kicad_sch, buck.kicad_sch, leds.kicad_sch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]
2026-03-14 Add a lot of TestPoints
    Move P-FET at the edge of board.
    [batt.kicad_sch, buck.kicad_sch, leds.kicad_sch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]
2026-03-14 Add MPN and stuff to TPS25940
    [power_switch.kicad_sch]
2026-03-14 Add distributor link for battery pack.
    [batt.kicad_sch]
2026-03-14 Resolv DRC warnings.
    [ledstrip.kicad_pcb]
2026-03-14 Fix a wrong capa and add MPN and stuff to STUSB4500
    [buck.kicad_sch, pwr.kicad_sch]
2026-03-14 Improve BOM: exclude uneeded parts, add some columns.
    [batt.kicad_sch, buck.kicad_sch, leds.kicad_sch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]
2026-03-14 Mark through-hole component "Do not place" in schematics.
    [leds.kicad_sch, ledstrip.kicad_pcb, ledstrip.kicad_sch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]
2026-03-14 Fix DRC
    [ledstrip.kicad_pcb]
2026-03-14 Install kicad-sch-api MCP server.
    Update parsing-kicad-schematics skill.
2026-03-14 Fix wrong footprint (C_0603 instead of R_0603)
    [batt.kicad_sch, ledstrip.kicad_pcb, pwr.kicad_sch]
2026-08-11 Update D1 with ST's replacement part.
    [pwr.kicad_sch]
2026-08-11 Generate mouser-compatible BOM in CI.
2026-08-11 Fix mouser BOM generation.
2026-08-11 Use exact MPN instead of "base" MPN for CL21A106KAYNNN(F)
    [batt.kicad_sch, buck.kicad_sch, ledstrip.kicad_sch]
2026-08-15 Add board picture in README
2026-10-15 Add skeleton for zephyr out of tree build.
    Custom board with STM32G030 SoC, UART connected.
    App hello world.
    JLink setup, so west flash should work.
    To be tested on real hardward once solder.
2026-11-08 Start doing 3D models: add missing 3D viewer to KiCAD.
